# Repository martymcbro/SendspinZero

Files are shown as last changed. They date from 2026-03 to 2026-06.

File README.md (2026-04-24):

# Minimalistic Sendspin Media Player for Home Assistant



A tiny Sendspin media player with **cover art display** and a **weather clock**, built around the **ESP32-S3 Zero**.

This project turns a small, inexpensive ESP32 board into a compact **audio receiver** for your amplifier, with a screen for album art, **song**, **artist**, and a weather clock when not playing, OR a Button to control with, or with nothing so you can hide it behind the tv/stereo.

Each version can be built with one of these options:

* Display
* No display
* Big button

That gives a total of **9 variants**:

Variants

---

## About the Project

This started as a fun experiment: I wanted to see if the **ESP32-S3 Zero** would work with Sendspin. Since it has **2 MB of PSRAM**, I figured it *might* be possible—and it turns out, it is.

Once that worked, I thought: instead of building yet another “Sendspin speaker”, why not make a **tiny receiver** for my amplifier?

So I:

* Replaced the **MAX98357** with a **PCM5102A DAC**
* Designed a custom case
* Added a display for **cover art** and a **weather clock**

…and this is the result 🙂

---

## Photos

<p align="center">
  
  
</p>

---

## Cost

All parts were sourced from AliExpress and added up to **just over $10** (last checked).

---

## Parts List

* **1 × ESP32-S3 Zero**
  [https://www.aliexpress.com/item/1005009890203011.html](https://www.aliexpress.com/item/1005009890203011.html)

  (be sure you select esp32-s3, not esp32-c3 which the page defaults to.)

* **1 × PCM5102A DAC**
  [https://www.aliexpress.com/item/1005008130629022.html](https://www.aliexpress.com/item/1005008130629022.html)

* **1 × 1.54" LCD screen**
  [https://www.aliexpress.com/item/1005008703777053.html](https://www.aliexpress.com/item/1005008703777053.html)

---

## Diagram & Pins Used

Wiring diagram

### ⚠️ Assembly Notes

* If you plan to mount everything inside the case, **do NOT solder header pins** to the DAC, ESP32, or display.
  → Solder wires directly to the boards instead, otherwise they won’t fit.

* If your display already has pins:
  → You may need to **bend two pins** slightly to make room for the audio jack.



---

## Pin Mapping

### ESP32-S3 → PCM5102A

| ESP32-S3 GPIO | PCM5102A Pin |
| --- | --- |
| GPIO4 | LRCK |
| GPIO5 | BCK |
| GPIO6 | DIN |

### ESP32-S3 → Display

| ESP32-S3 GPIO | Display Pin |
| --- | --- |
| GPIO7 | SCL |
| GPIO8 | SDA |
| GPIO9 | RST |
| GPIO10 | DC |
| GPIO11 | BL |

### Power (both modules)

* **GND**
* **3.3V**

### Important DAC Setup

Make sure to:

* Solder the pads on the **back of the PCM5102A** (as shown below)
* Solder the bridge near **SCK on the front** (some boards come pre-soldered)



---

## Toslink (Optical Audio) Version

This version has **no display** and is the easiest build—**under $10** 🙂

(For display or button versions, pin usage is the same)

Toslink version

Your soundbar will love you for it 😉
3D files are in [`3D_Files`](3D_Files)

### Pin Mapping

### ESP32-S3 → Toslink Connector

| ESP32-S3 GPIO | TOSLINK |
| --- | --- |
| GPIO4 | VIN (DATA) |
| 3.3V | VCC |
| GND | GND |

Pins

### Parts

* Single: [https://www.aliexpress.com/item/1005011593001325.html](https://www.aliexpress.com/item/1005011593001325.html)
* 1–10 pcs: [https://www.aliexpress.com/item/1005008393864163.html](https://www.aliexpress.com/item/1005008393864163.html)
* Cables: [https://www.aliexpress.com/item/1005008202856228.html](https://www.aliexpress.com/item/1005008202856228.html)

- 1 × M2.6×10 self-tapping screw

⚠️ **Important:** Select **"Transmitting end" (A1)**

---

## Coax (Digital Audio) Version

Simplest version of all: **just two wires and a resistor**.

Coax version

3D files are in [`3D_Files`](3D_Files)

### Pin Mapping

### ESP32-S3 → RCA Connector

| ESP32-S3 GPIO | RCA |
| --- | --- |
| GPIO4 | VIN (DATA) |
| GND | GND |

### Parts

* 1 pcs. 332-470ohm resistor [https://www.aliexpress.com/item/1005005252979796.html](https://www.aliexpress.com/item/1005005252979796.html)

* RCA female: [https://www.aliexpress.com/item/1005010424983352.html](https://www.aliexpress.com/item/1005010424983352.html)
* Cables: [https://www.aliexpress.com/item/1005008202856228.html](https://www.aliexpress.com/item/1005008202856228.html)

---

## Button Version

Instead of a display, you can use a **large illuminated button**.

### Controls

* **Single click** → Play / pause
* **Double click** → Next track
* **Triple click** → Previous track
* **Hold** → Toggle Sendspin / Home Assistant control mode

In HA mode, clicks are exposed for automations.



3D files are in [`3D_Files`](3D_Files)

### Pin Mapping

| ESP32-S3 GPIO | Button |
| --- | --- |
| GPIO1 | 1 |
| GPIO2 | 3 |
| GPIO3 | 4 |
| GND | 2 + 5  |



### Part

**22mm Bicolor (RG) Black 3–6V**
[https://www.aliexpress.com/item/1005004920346156.html](https://www.aliexpress.com/item/1005004920346156.html)

---

## SendspinZero-Control (Knob + Button + Display)

This version uses a combo board with a **rotary encoder + button + display i found cheap on aliexpress**.



3D files are in [`3D_Files`](3D_Files)

### Additional Pins

(Same as display version + these)

| ESP32-S3 GPIO | Combo Board |
| --- | --- |
| GPIO12 | TRA |
| GPIO13 | TRB |
| GPIO43 (TX) | PSH |
| GPIO44 (RX) | KO |

(TX = GPIO43, RX=GPIO44 on the zero board)



### Part

ESP32-S3 Zero and PCM5102A as above +

[https://www.aliexpress.com/item/1005009900611104.html](https://www.aliexpress.com/item/1005009900611104.html)

---

## Display + Button Version



3D files are in [`3D_Files`](3D_Files)

### Pin Mapping

Same as SendspinZero-Display + SendspinZero-Button

### Parts

same components as the other versions (esp32-s3 + PCM5102A DAC + Button) +

* 1.9" screen: [https://www.aliexpress.com/item/1005007098895718.html](https://www.aliexpress.com/item/1005007098895718.html)

---

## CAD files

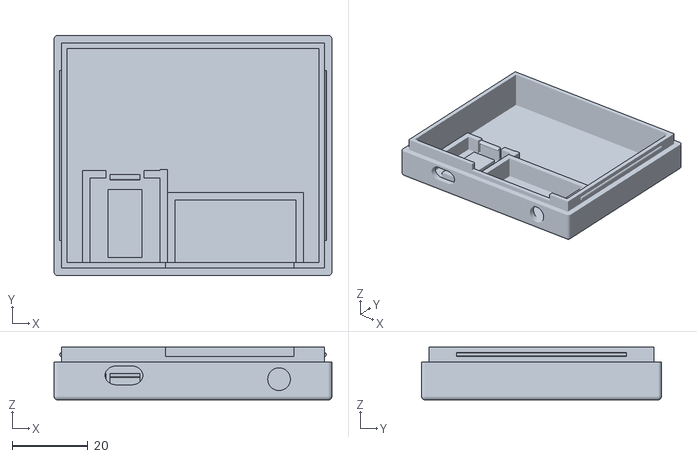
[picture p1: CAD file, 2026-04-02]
3D_Files/SendspinZero-Control-back.stl
73.5 x 63.5 x 14.0

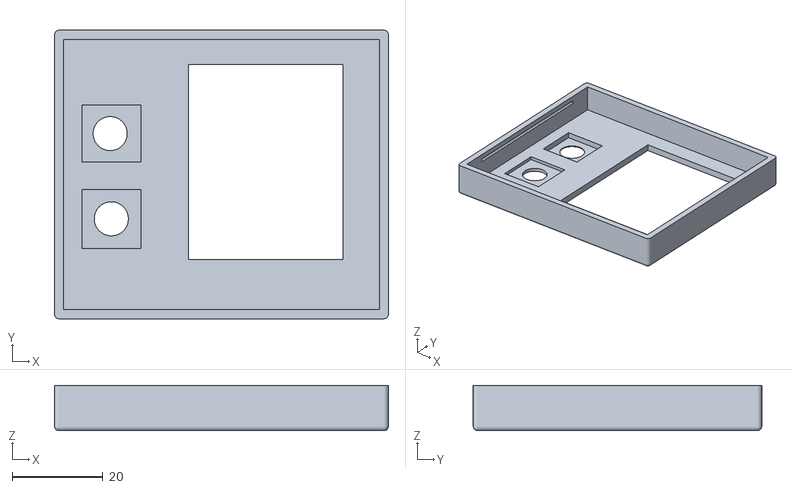
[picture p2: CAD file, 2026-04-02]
3D_Files/SendspinZero-Control-front.stl
73.5 x 63.5 x 10.0

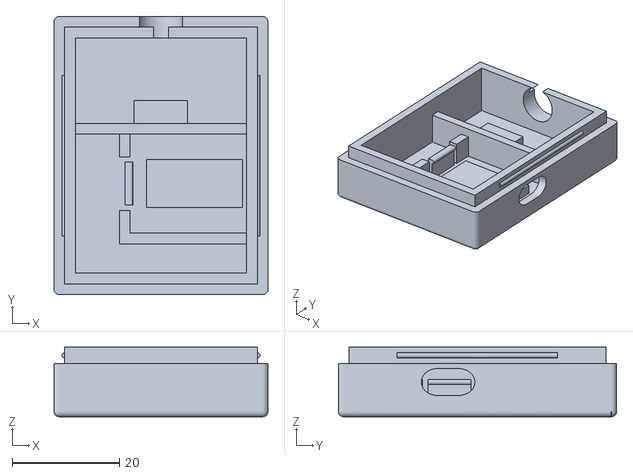
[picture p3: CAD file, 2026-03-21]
3D_Files/SendspinZero-Coax-back.stl
40.0 x 52.0 x 13.0

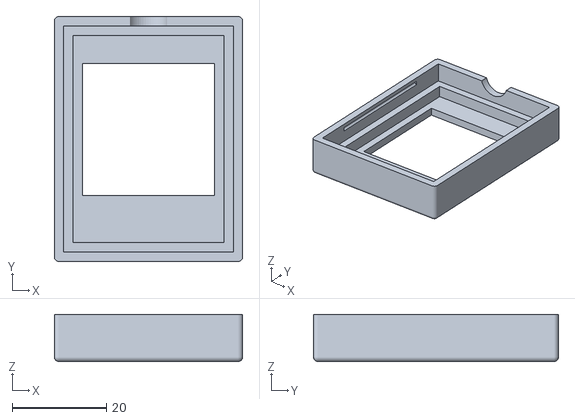
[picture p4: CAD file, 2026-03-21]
3D_Files/SendspinZero-Coax-front-display.stl
40.0 x 52.0 x 10.0

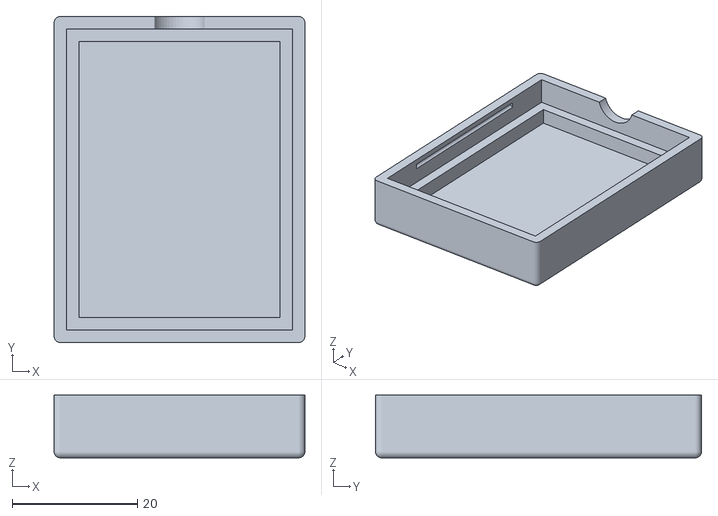
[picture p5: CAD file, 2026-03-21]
3D_Files/SendspinZero-Coax-front-nodisplay.stl
40.0 x 52.0 x 10.0

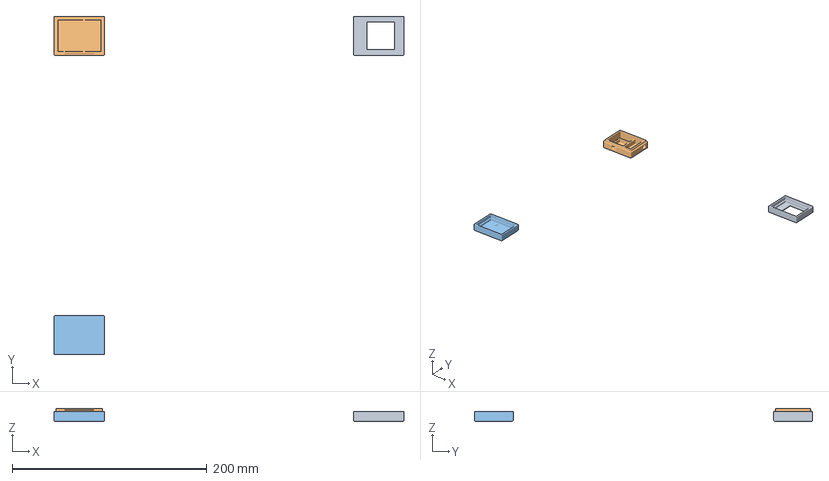
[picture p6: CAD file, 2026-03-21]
3D_Files/SendspinZero-Analog.3mf
359.2 x 347.2 x 13.0 mm
sendspin-zero-case-a.stl
sendspin-zero-case-b.stl
sendspin-zero-case-a-nodisplay.stl

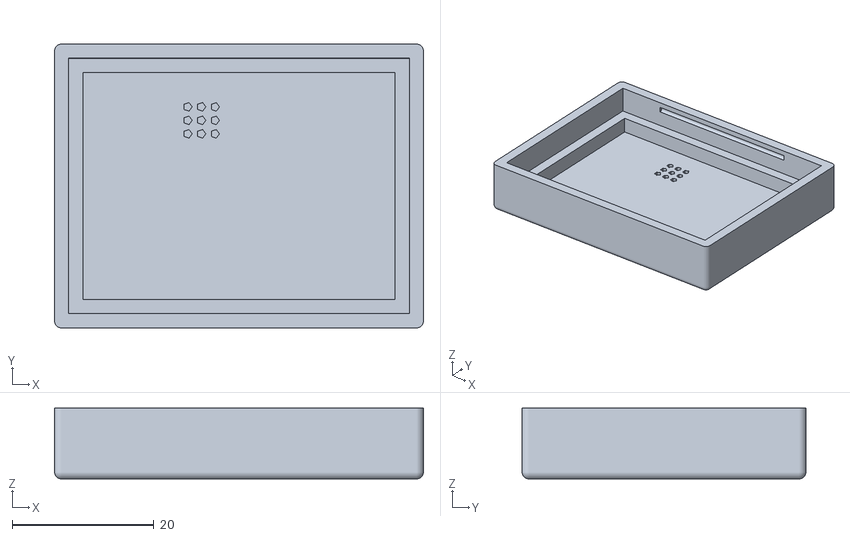
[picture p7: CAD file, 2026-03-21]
3D_Files/SendspinZero-Analog-front-nodisplay.stl
52.0 x 40.0 x 10.0

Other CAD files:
3D_Files/SendspinZero-Analog-front-display.stl
3D_Files/SendspinZero-Analog-back.stl
3D_Files/SendspinZero-Toslink-front-display.stl
3D_Files/SendspinZero-Coax.3mf

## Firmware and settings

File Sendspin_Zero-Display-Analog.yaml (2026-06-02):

## SendspinZero Display Analog version
substitutions:
  name: sendspin-zero
  friendly_name: Sendspin Zero Display

## SETTINGS ######################################################################################################################################

  # Startup sound, options are: Home_Connected or Home_Connected_Male
  startup_sound_file: Home_Connected

  # your home assistant weather entity, in most cases the same.
  ha_weather_entity: weather.forecast_home
  timezone: Europe/Berlin

  media_sample_rate: 48000

  # Rotating the display, uncomment the block you need (default 0 degree)

  # 0 degree
  display_swap_xy: "false"
  display_mirror_x: "false"
  display_mirror_y: "false"
  display_offset_width: "0"
  display_offset_height: "0"

  # 180 degree
  # display_swap_xy: "false"
  # display_mirror_x: "true"
  # display_mirror_y: "true"
  # display_offset_width: "0"
  # display_offset_height: "80"

  # I2S audio pins
  i2s_lrclk_pin: GPIO4
  i2s_bclk_pin: GPIO5
  i2s_dout_pin: GPIO6

  # RGB LED
  rgb_led_pin: GPIO21

  # SPI pins (for display)
  spi_clk_pin: GPIO7
  spi_mosi_pin: GPIO8

  # Display control pins
  display_dc_pin: GPIO10
  display_reset_pin: GPIO9
  display_bl_pin: GPIO11

## SENDSPIN SETTINGS #############################################################################################################################

external_components:

  - source: github://pr#16057
    components: [generic_image, sendspin]
    refresh: 1h

## END OF SETTINGS ###############################################################################################################################

esphome:
  name: ${name}
  friendly_name: ${friendly_name}
  min_version: 2026.5.0
  name_add_mac_suffix: true
  project:
    name: realdeco.sendspin_zero
    version: "2026.5.0"
  on_boot:
    priority: -100
    then:
      - script.execute: led_red
      - lvgl.page.show: idle_page

esp32:
  variant: esp32s3
  flash_size: 4MB
  framework:
    type: esp-idf

logger:
  level: WARN

debug:
  update_interval: 5s

api:
  on_client_connected:
    - lambda: |-
        if (!id(boot_sound_played)) {
          id(boot_sound_played) = true;
          if (id(startup_sound_switch).state) {
            id(play_sound)->execute(true, std::string("ready_sound"));
          }
        }
ota:
  platform: esphome
  password: !secret ota_password

wifi:
  ap:

improv_serial:

psram:
  mode: quad
  speed: 80MHz

captive_portal:

time:
  - platform: homeassistant
    id: homeassistant_time
    timezone: ${timezone}

globals:
  - id: sendspin_album_art_valid
    type: bool
    restore_value: no
    initial_value: "false"
  - id: boot_sound_played
    type: bool
    restore_value: no
    initial_value: "false"
  - id: boot_announce_active
    type: bool
    restore_value: no
    initial_value: "false"
  - id: weather_available
    type: bool
    restore_value: no
    initial_value: "false"

image:
  - file: https://raw.githubusercontent.com/RealDeco/xiaozhi-esphome/main/images/Gwen/240x240/playing.png
    id: fallback_playing_image
    resize: 216x216
    type: RGB565
    dither: NONE

generic_image:
  - platform: sendspin
    id: sendspin_album_art
    format: jpeg # <<< NEW
    type: RGB565
    resize: 216x216
    source: ALBUM # <<< NEW
    on_image_display: # <<< NEW
      - script.stop: album_art_timeout_fallback
      - lambda: |-
          id(sendspin_album_art_valid) = true;
      - lvgl.image.update:
          id: album_art_widget
          src: sendspin_album_art
    on_image_error:
      - lambda: |-
          id(sendspin_album_art_valid) = false;
      - lvgl.image.update:
          id: album_art_widget
          src: fallback_playing_image

sendspin:
  id: sendspin_hub
  task_stack_in_psram: false

i2s_audio:
  - id: i2s_audio_bus
    i2s_lrclk_pin: ${i2s_lrclk_pin}
    i2s_bclk_pin: ${i2s_bclk_pin}

speaker:
  - platform: i2s_audio
    id: box_speaker
    i2s_audio_id: i2s_audio_bus
    i2s_dout_pin: ${i2s_dout_pin}
    dac_type: external
    channel: stereo

  - platform: mixer
    id: mixing_speaker
    output_speaker: box_speaker
    num_channels: 2
    task_stack_in_psram: true
    source_speakers:
      - id: announcement_mixing_input
      - id: media_mixing_input

  - platform: resampler
    id: announcement_resampling_speaker
    output_speaker: announcement_mixing_input
    sample_rate: ${media_sample_rate}
    bits_per_sample: 16

  - platform: resampler
    id: media_resampling_speaker
    output_speaker: media_mixing_input
    sample_rate: ${media_sample_rate}
    bits_per_sample: 16

audio_file:
  - id: ready_sound
    file: https://github.com/RealDeco/xiaozhi-esphome/raw/main/sounds/${startup_sound_file}.flac

media_source:
  - platform: audio_file
    id: audio_file_announcement_source
  - platform: audio_http
    id: http_announcement_source
  - platform: audio_http
    id: http_media_source
  - platform: sendspin
    id: sendspin_media_source
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

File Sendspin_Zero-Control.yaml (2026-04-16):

substitutions:
  name: esphome-web-e83240
  friendly_name: Sendspin Zero Control

## SETTINGS ######################################################################################################################################

  # Startup sound, options are: Home_Connected or Home_Connected_Male
  startup_sound_file: Home_Connected

  # your home assistant weather entity, in most cases the same.
  ha_weather_entity: weather.forecast_home

  # Light entity or group to be controlled by the rotary knob
  # for this to work You also need to enable “Allow the device to perform Home Assistant actions” for this ESPHome device in Home Assistant.
  control_device_1: light.ceiling
  control_devicename_1: "Ceiling 1"
  control_device_2: light.ceiling_2
  control_devicename_2: "Ceiling 2"
  control_device_3: light.desklight_light
  control_devicename_3: "Desk Light"
  control_device_4: light.hue_p45_7_light
  control_devicename_4: "Prt. Light"
  control_device_5: light.hue_p45_8_light
  control_devicename_5: "Blue Lamp"
  control_device_6: light.livingroom_all_lights
  control_devicename_6: "All Light"

  # Home Assistant button entity triggered by normal-button triple click.
  favorite_button_entity: button.sensspin_zero_control_favorite_current_song

  # Home Assistant Media Player entity for playing streams (e.g. via Music Assistant)
  ha_media_player_entity: media_player.sensspin_zero_control

  # Media Menu Items Configuration
  media_item_count: "6" # Increase this when adding more items below (max 10)

  # Media links and names for menu
  media_name_1: "Random 500"
  media_url_1: "library://playlist/45"
  media_name_2: "Neil Diamond"
  media_url_2: "library://playlist/72"
  media_name_3: "Tommy Steele"
  media_url_3: "library://playlist/68"
  media_name_4: "Radio: P5"
  media_url_4: "http://live-icy.gss.dr.dk:8000/A/A25L.mp3"
  media_name_5: "Radio: Boost"
  media_url_5: "http://6434.cloudrad.io:8066/live"
  media_name_6: "Radio: Smooth Chill"
  media_url_6: "https://ice-sov.musicradio.com/SmoothChillMP3"

  # Available slots for future expansion (up to 10)
  media_name_7: "Unused 7"
  media_url_7: "unused"
  media_name_8: "Unused 8"
  media_url_8: "unused"
  media_name_9: "Unused 9"
  media_url_9: "unused"
  media_name_10: "Unused 10"
  media_url_10: "unused"


## ROTATIO: THIS PART IS ONLY NEEDED IF YOU TURNED DISPLAY AROUND IN CASE ########################################################################

  # 0 degree (default)
  display_swap_xy: "false"
  display_mirror_x: "false"
  display_mirror_y: "false"
  display_offset_width: "0"
  display_offset_height: "0"

  # 180 degree
  # display_swap_xy: "false"
  # display_mirror_x: "true"
  # display_mirror_y: "true"
  # display_offset_width: "0"
  # display_offset_height: "80"

## SENDSPIN SETTINGS #############################################################################################################################

packages:
  extcomp:
    url: https://github.com/RealDeco/xiaozhi-esphome.git
    ref: main
    refresh: 0s
    files:
      - devices/Under_Development/Modular/HW/sendspin-external_components.yaml

## AUDIO SETTINGS ################################################################################################################################

  hw: #ANALOG
    url: https://github.com/RealDeco/SendspinZero.git
    ref: main
    refresh: 0s
    files:
      - analog_speaker_config.yaml

#  hw: #DIGITAL
#    url: https://github.com/RealDeco/SendspinZero.git
#    ref: main
#    refresh: 0s
#    files:
#      - digital_speaker_config.yaml

## END OF SETTINGS ###############################################################################################################################


esphome:
  name: ${name}
  friendly_name: ${friendly_name}
  min_version: 2026.4.0
  name_add_mac_suffix: false
  on_boot:
    priority: -100
    then:
      - script.execute: led_red
      - lvgl.page.show: idle_page

esp32:
  variant: esp32s3
  flash_size: 4MB
  framework:
    type: esp-idf

logger:
  level: WARN
  baud_rate: 0

api:
  on_client_connected:
    - lambda: |-
        if (!id(boot_sound_played)) {
          id(boot_sound_played) = true;
          if (id(startup_sound_switch).state) {
            id(play_sound)->execute(true, std::string("ready_sound"));
          }
        }
    - delay: 5s
    - script.execute: fetch_daily_forecast

ota:
  - platform: esphome

wifi:
  ssid: !secret wifi_ssid
  password: !secret wifi_password
  ap:
    password: "RZ7D3EzJdPM6"

psram:
  mode: quad
  speed: 80MHz

captive_portal:

time:
  - platform: homeassistant
    id: homeassistant_time
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

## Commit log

2026-03-07 Add configuration for Sendspin Zero Toslink
    This YAML file defines the configuration for the Sendspin Zero Toslink device, including components for audio playback, Wi-Fi settings, and LED control.
2026-03-08 Modify README with updated GPIO mapping and image
    Updated GPIO pin mapping for PCM5102A and added image reference for toslink connector.
2026-03-08 Update pin mapping for ESP32-S3 to TOSLINK plug
2026-03-30 Add Sendspin Zero Button configuration
2026-03-30 Update README with Toslink, Coax, and button options
    Added details about Toslink and Coax versions, including pin mappings and links to parts. Introduced a new button option for the project.
2026-04-02 Add Sendspin Zero Control configuration
    first test version for this display/rotary/button board.
2026-04-05 Clarify ESP32 selection in README
    Added a note to select ESP32-S3 instead of ESP32-C3.
2026-04-24 Update GPIO pin labels in README
    Clarified GPIO pin labels for ESP32-S3 Combo Board.
